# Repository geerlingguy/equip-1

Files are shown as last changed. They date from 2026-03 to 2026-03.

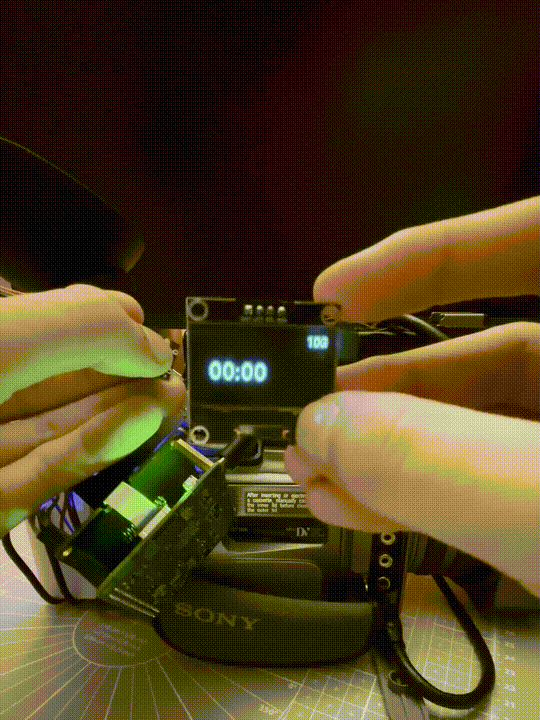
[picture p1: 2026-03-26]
design/media/interface.gif

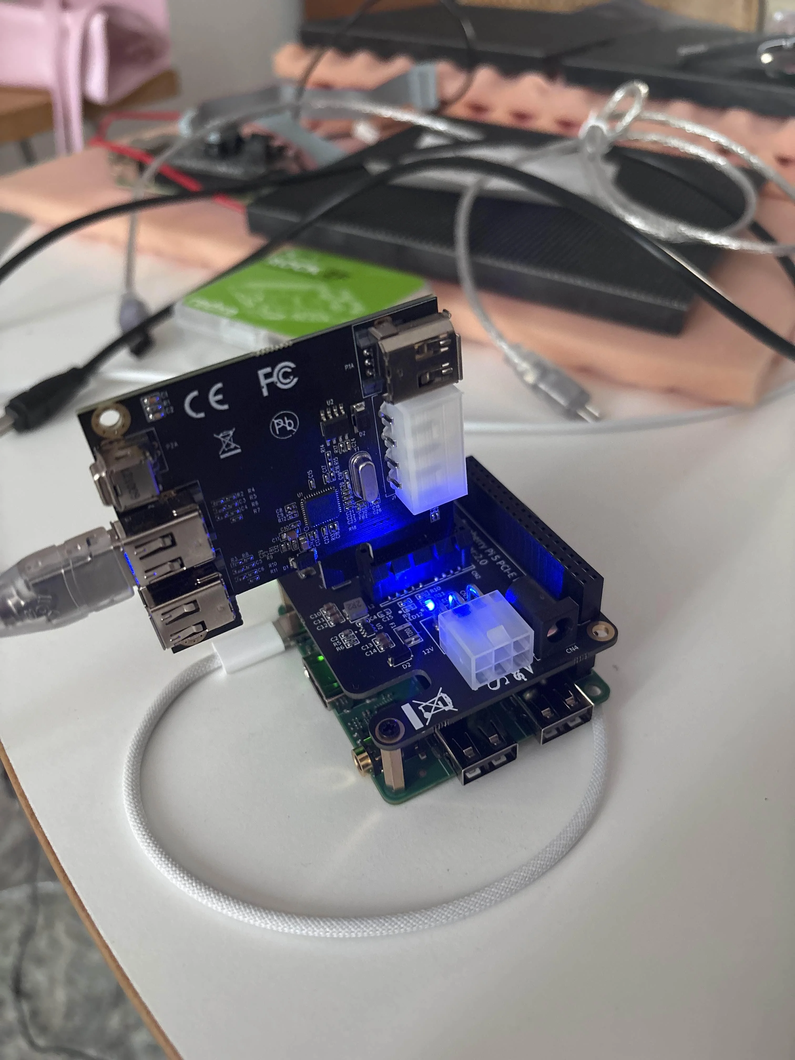
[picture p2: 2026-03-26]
design/media/device.png

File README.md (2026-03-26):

# Equip-1

Compact DV recorder. Connects to any FireWire camcorder and saves footage directly to microSD. No laptop required.

Supports MiniDV, DVCAM, DVCPRO, Digital8, and HDV. Controls the tape deck on supported cameras, so you can digitize an entire tape automatically. Pressing record on the camera triggers capture on the Equip-1.

Built around the [Radxa ROCK 2F](https://radxa.com/products/rock2/2f/) and our custom **Firehat** — a FireWire HAT with a VIA VT6315N controller connected via PCIe over FPC.

The Firehat is also available standalone. It works as a HAT for the ROCK 2F, Pi 5 and other SBCs.

## Hardware

**Equip-1**

- Radxa ROCK 2F (Rockchip RK3528A, quad-core ARM Cortex-A53, 2 GB RAM, 8 GB eMMC)
- Firehat (see below)
- MicroSD storage
- USB-C power input, 5V
- HDMI output
- WiFi 6, Bluetooth 5.4
- 2x USB 2.0 Type-A
- 60 mm x 70 mm x 25 mm, ~100 g

**Firehat**

- VIA VT6315N FireWire controller
- 6-pin FireWire port (DVin)
- PCIe 2.0 x1 via FPC connector
- 40-pin 2.54 mm GPIO header (Raspberry Pi-compatible)
- OLED display
- 3x SMD buttons, RGB LED, buzzer
- 56 mm x 70 mm x 12 mm, ~25 g

## Open Source

Hardware is licensed under [CERN OHL-S](https://ohwr.org/cern_ohl_s_v2.txt). Software is licensed under GPL. Derivatives must be released under the same licenses.

## Community

Discord: [discord.gg/jfMNN83wep](https://discord.gg/wpXmcb5mvK)

If you like this project and want to know more about the development and future steps, or even build your own version, feel free to join this discord. We are a small community building objects with computers!

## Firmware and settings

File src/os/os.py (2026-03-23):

import time
import shutil
import subprocess
import os
import socket
from periphery import GPIO
from luma.core.interface.serial import i2c
from luma.oled.device import sh1106
from PIL import Image, ImageDraw, ImageFont

# Set to "rock2f" or "rpi"
BOARD = os.environ.get("EQUIP_1_BOARD_TYPE", "rock2f")

if BOARD == "rock2f":
    I2C_PORT = 0
    GPIOCHIP = "/dev/gpiochip4"
    BUZZER = 19
    BTN_UP = 15
    BTN_SELECT = 16
    BTN_DOWN = 22
elif BOARD == "rpi":
    I2C_PORT = 1
    GPIOCHIP = "/dev/gpiochip4"
    BUZZER = 12
    BTN_UP = 22
    BTN_SELECT = 27
    BTN_DOWN = 17
else:
    raise ValueError(f"Unknown BOARD: {BOARD}")


class RecorderState:
    def __init__(self, output_dir=None):
        if output_dir is None:
            output_dir = os.path.expanduser("~/captures")
        self.mode = "idle"
        self.start_time = None
        self.process = None
        self.output_dir = output_dir
        os.makedirs(output_dir, exist_ok=True)

    @property
    def camera_connected(self):
        # Check if a FireWire camera is connected (fw1 exists when camera plugged in)
        return os.path.exists("/dev/fw1")

    def toggle(self):
        if self.mode == "idle":
            if not self.camera_connected:
                return
            self.mode = "recording"
            self.start_time = time.time()
            timestamp = time.strftime("%Y%m%d_%H%M%S")
            self.process = subprocess.Popen(
                ["dvgrab", "-buffers", "20",
                 f"{self.output_dir}/capture_{timestamp}-"],
                stdout=subprocess.PIPE,
                stderr=subprocess.PIPE
            )
        else:
            self.mode = "idle"
            if self.process:
                self.process.terminate()
                try:
                    self.process.wait(timeout=5)
                except subprocess.TimeoutExpired:
                    self.process.kill()
                self.process = None
            self.start_time = None

    @property
    def is_recording(self):
        return self.mode == "recording"

    @property
    def elapsed_text(self):
        if not self.is_recording or self.start_time is None:
            return "00:00:00"
        elapsed = time.time() - self.start_time
        hh, rem = divmod(int(elapsed), 3600)
        mm, ss = divmod(rem, 60)
        return f"{hh:02}:{mm:02}:{ss:02}"

    @property
    def recording_minutes_left(self):
        _, _, free = shutil.disk_usage(self.output_dir)
        # DV video around 3.6 MB/s = 216 MB/min
        # How could we know bitrate of different cameras?
        minutes = free / (216 * 1024 * 1024)
        return f"{int(minutes)}m"


class Display:
    def __init__(self):
        serial = i2c(port=I2C_PORT, address=0x3C)
        self.device = sh1106(serial)
        self.font_medium = ImageFont.truetype(
            "fonts/Px437_DOS-V_re_JPN12.ttf", 12
        )
        self.font_big = ImageFont.truetype(
            "fonts/Px437_Paradise132_7x16.ttf", 34
        )

    def clear(self):
        img = Image.new("1", self.device.size)
        self.device.display(img)

    def render(self, draw_func):
        img = Image.new("1", self.device.size)
        draw = ImageDraw.Draw(img)
        draw_func(draw, self.device.width, self.device.height)
        self.device.display(img)


class Screen:    
    def __init__(self, app):
        self.app = app
    
    def on_select(self):
        pass
    
    def can_navigate(self):
        return True
    
    def render(self, draw, width, height):
        pass


class RecordingScreen(Screen):
    def on_select(self):
        self.app.recorder.toggle()
    
    def can_navigate(self):
        return not self.app.recorder.is_recording
    
    def render(self, draw, width, height):
        recorder = self.app.recorder
        font_medium = self.app.display.font_medium
        font_big = self.app.display.font_big
        
        # No camera connected
        if not recorder.camera_connected and not recorder.is_recording:
            draw.text((0, 0), "RECORD", font=font_medium, fill=255)
            no_cam = "NO CAM"
            bbox = draw.textbbox((0, 0), no_cam, font=font_big)
            x = (width - (bbox[2] - bbox[0])) // 2
            draw.text((x, 28), no_cam, font=font_big, fill=255)
            return
        
        # Recording indicator
        if recorder.is_recording:
            if int(time.time() * 2) % 2:
                draw.ellipse((0, 2, 10, 12), fill=255)
            draw.text((14, 0), "REC", font=font_medium, fill=255)
        else:
            draw.text((0, 0), "RECORD", font=font_medium, fill=255)
        
        # Minutes left (top right)
        mins_left = recorder.recording_minutes_left
        bbox = draw.textbbox((0, 0), mins_left, font=font_medium)
        draw.text((width - (bbox[2] - bbox[0]), 0), mins_left, font=font_medium, fill=255)
        
        # Timer (center)
        timer = recorder.elapsed_text
        bbox = draw.textbbox((0, 0), timer, font=font_big)
        x = (width - (bbox[2] - bbox[0])) // 2
        draw.text((x, 28), timer, font=font_big, fill=255)


class StorageScreen(Screen):
    def render(self, draw, width, height):
        font_medium = self.app.display.font_medium
        
        draw.text((0, 0), "STORAGE", font=font_medium, fill=255)
        
        total, used, free = shutil.disk_usage(self.app.recorder.output_dir)
        total_gb = total / (1024**3)
        used_gb = used / (1024**3)
        free_gb = free / (1024**3)
        percent = (used / total) * 100
        
        draw.text((0, 16), f"Total: {total_gb:.1f} GB", font=font_medium, fill=255)
        draw.text((0, 30), f"Used:  {used_gb:.1f} GB ({percent:.0f}%)", font=font_medium, fill=255)
        draw.text((0, 44), f"Free:  {free_gb:.1f} GB", font=font_medium, fill=255)


class NetworkScreen(Screen):
    def get_ip(self):
        try:
            s = socket.socket(socket.AF_INET, socket.SOCK_DGRAM)
            s.connect(("8.8.8.8", 80))
            ip = s.getsockname()[0]
            s.close()
            return ip
        except:
            return "No connection"
    
    def render(self, draw, width, height):
        font_medium = self.app.display.font_medium
        
        draw.text((0, 0), "NETWORK", font=font_medium, fill=255)
        
        ip = self.get_ip()
        draw.text((0, 20), "IP Address:", font=font_medium, fill=255)
        draw.text((0, 34), ip, font=font_medium, fill=255)


class USBGadgetScreen(Screen):
    def __init__(self, app):
        super().__init__(app)
        self.enabled = False
    
    def on_select(self):
        self.enabled = not self.enabled
        if self.enabled:
            subprocess.run(["modprobe", "g_mass_storage", 
                          f"file={self.app.recorder.output_dir}", "removable=1"],
                          capture_output=True)
        else:
            subprocess.run(["modprobe", "-r", "g_mass_storage"], capture_output=True)
    
    def render(self, draw, width, height):
        font_medium = self.app.display.font_medium
        
        draw.text((0, 0), "USB GADGET", font=font_medium, fill=255)
        
        status = "ENABLED" if self.enabled else "DISABLED"
        draw.text((0, 20), "Mass Storage Mode:", font=font_medium, fill=255)
        draw.text((0, 34), status, font=font_medium, fill=255)
        draw.text((0, 50), "Press to toggle", font=font_medium, fill=255)


class PowerScreen(Screen):
    def __init__(self, app):
        super().__init__(app)
        self.options = ["Shutdown", "Reboot", "Cancel"]
        self.selected = 0
        self.confirm_mode = False
    
    def on_select(self):
        if not self.confirm_mode:
            self.confirm_mode = True
        else:
            if self.options[self.selected] == "Shutdown":
                subprocess.run(["sudo", "shutdown", "-h", "now"])
            elif self.options[self.selected] == "Reboot":
                subprocess.run(["sudo", "reboot"])
            else:
                self.confirm_mode = False
                self.selected = 0
    
    def on_up(self):
        if self.confirm_mode:
            self.selected = (self.selected - 1) % len(self.options)
            return True
        return False
    
    def on_down(self):
        if self.confirm_mode:
            self.selected = (self.selected + 1) % len(self.options)
            return True
        return False
    
    def render(self, draw, width, height):
        font_medium = self.app.display.font_medium
        
        draw.text((0, 0), "POWER", font=font_medium, fill=255)
        
        if not self.confirm_mode:
            draw.text((0, 20), "Press to select:", font=font_medium, fill=255)
            draw.text((0, 34), "Shutdown / Reboot", font=font_medium, fill=255)
        else:
            for i, opt in enumerate(self.options):
                y = 16 + i * 16
                prefix = "> " if i == self.selected else "  "
                draw.text((0, y), prefix + opt, font=font_medium, fill=255)


class TestScreen(Screen):
    def render(self, draw, width, height):
        draw.rectangle((0, 0, width, height), fill=255)



class Buzzer:
    def __init__(self, chip=GPIOCHIP, line=BUZZER):
        self.gpio = GPIO(chip, line, "out")
    
    def beep(self, duration=0.08, freq=2048):
        cycles = int(duration * freq)
        half_period = 1.0 / freq / 2
        for _ in range(cycles):
            self.gpio.write(True)
            time.sleep(half_period)
            self.gpio.write(False)
            time.sleep(half_period)
    
    def close(self):
        self.gpio.close()


class Button:
    def __init__(self, chip, line):
        self.gpio = GPIO(chip, line, "in")
        self.last_state = True
        self.last_press = 0

    def pressed(self):
        current = self.gpio.read()
        now = time.time()

        if self.last_state and not current and (now - self.last_press) > 0.3:
            self.last_press = now
            self.last_state = current
            return True

        self.last_state = current
        return False

    def close(self):
        self.gpio.close()


class Buttons:
    def __init__(self):
        self.up = Button(GPIOCHIP, BTN_UP)
        self.select = Button(GPIOCHIP, BTN_SELECT)
        self.down = Button(GPIOCHIP, BTN_DOWN)
 
    def close(self):
        self.up.close()
        self.select.close()
        self.down.close()


class App:
    def __init__(self):
        self.recorder = RecorderState()
        self.display = Display()
        self.buttons = Buttons()
        self.buzzer = Buzzer()
        
        self.screens = [
            #TestScreen(self),
            RecordingScreen(self),
            StorageScreen(self),
            NetworkScreen(self),
            #USBGadgetScreen(self),
            PowerScreen(self),
        ]
        self.current_screen_idx = 0
    
    @property
    def current_screen(self):
        return self.screens[self.current_screen_idx]
    
    def navigate_up(self):
        if hasattr(self.current_screen, 'on_up') and self.current_screen.on_up():
            return
        
        if self.current_screen.can_navigate():
            self.current_screen_idx = (self.current_screen_idx - 1) % len(self.screens)
    
    def navigate_down(self):
        if hasattr(self.current_screen, 'on_down') and self.current_screen.on_down():
            return
        
        if self.current_screen.can_navigate():
            self.current_screen_idx = (self.current_screen_idx + 1) % len(self.screens)
    
    def run(self):
        try:
            while True:
                if self.buttons.up.pressed():
                    self.buzzer.beep()
                    self.navigate_up()
                
                if self.buttons.down.pressed():
                    self.buzzer.beep()
                    self.navigate_down()
                
                if self.buttons.select.pressed():
                    self.buzzer.beep()
                    self.current_screen.on_select()
                
                self.display.render(self.current_screen.render)
                time.sleep(0.05)
        
        except KeyboardInterrupt:
            pass
        finally:
            if self.recorder.is_recording:
                self.recorder.toggle()
            self.buttons.close()
            self.buzzer.close()


def main():
    app = App()
    app.run()

if __name__ == "__main__":
    main()

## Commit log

2026-03-02 prototype os update
2026-03-02 rm led references
2026-03-23 Fixes #6: Allow board type selection via env var.
    [os.py]
2026-03-26 added firehat schematics
    [firehat.kicad_sch]
